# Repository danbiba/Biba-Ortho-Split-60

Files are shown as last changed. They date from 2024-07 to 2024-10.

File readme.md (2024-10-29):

# handwired/biba60




A 60% Ortholiner keyboard that can be used in a traditional form factor or split.

* Keyboard Maintainer: [Daniel Biba](https://github.com/danbiba)
* Hardware Supported: Arduino Pro Micro
* Hardware Availability: 3D Printable

## Keymap

Default Layer

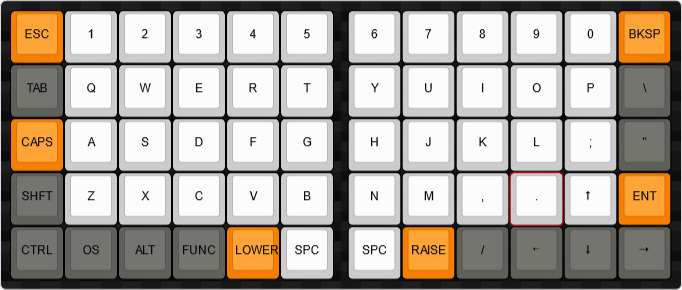
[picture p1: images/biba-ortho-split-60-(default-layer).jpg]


Lower Layer

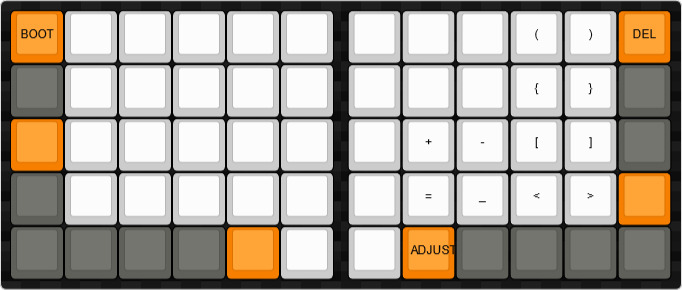
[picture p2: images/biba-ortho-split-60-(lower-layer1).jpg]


Raise Layer

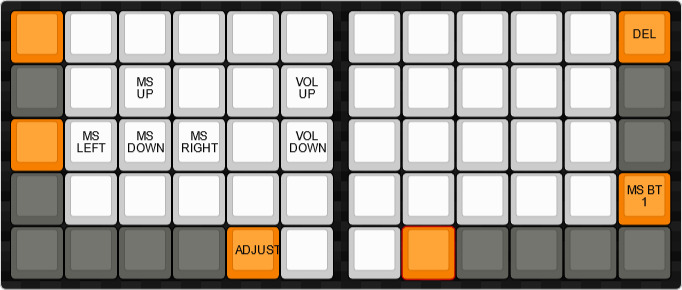
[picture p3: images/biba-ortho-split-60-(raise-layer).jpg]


Adjust Layer

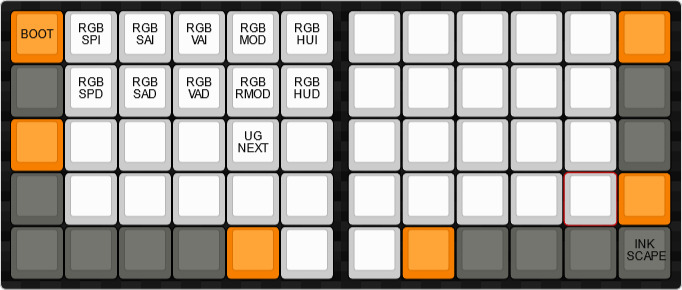
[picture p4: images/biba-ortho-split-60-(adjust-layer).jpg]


Function Layer

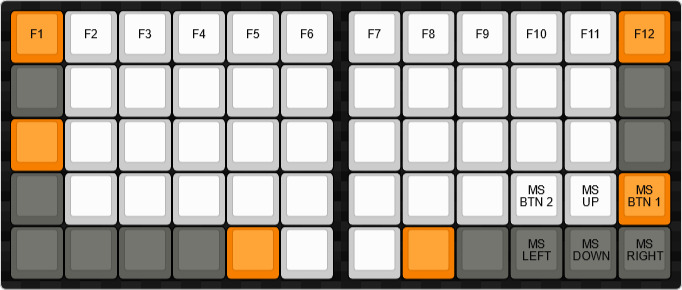
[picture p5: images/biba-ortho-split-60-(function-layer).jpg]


Inkscape Layer

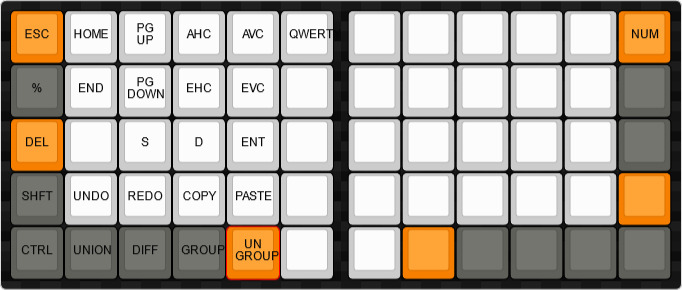
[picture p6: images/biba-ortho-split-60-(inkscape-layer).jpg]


## Setup
Place the code posted here in your qmk_firmware/keyboards/handwired/biba60 folder

Make example for this keyboard (after setting up your build environment):

    qmk compile -kb handwired/biba60 -km default

See the [build environment setup](https://docs.qmk.fm/#/getting_started_build_tools) and the [make instructions](https://docs.qmk.fm/#/getting_started_make_guide) for more information. Brand new to QMK? Start with our [Complete Newbs Guide](https://docs.qmk.fm/#/newbs).

## Bootloader

Enter the bootloader in 3 ways:

* Lower + 0,0 (if only one board is plugged in it defaults to the LEFT)
* Adjust + 0,0
* Short out pins RST and GND on the Pro Micro

## Bill of Materials
Diodes (x60): https://www.amazon.com/dp/B079KJ91JZ/?coliid=IU9YRLAUD8BYV&colid=GI9LV354TQGI&psc=1&ref_
    
Pro Mico Boards (x2): https://www.amazon.com/dp/B0B6HYLC44/?coliid=I2J23DRCUG601T&colid=GI9LV354TQGI&psc=1&ref_
    
LED Light Strips: https://www.amazon.com/dp/B01CDTED80/?coliid=I2PFQBWAX38YSN&colid=GI9LV354TQGI&psc=1&ref_
    
Switches (Epomake Wisteria Tactiles x60): https://www.amazon.com/dp/B0BZYG13Q5/?coliid=I11VNZPVFJJRM6&colid=GI9LV354TQGI&psc=1&ref_
    
2.5mm TRS cable (1x): https://www.amazon.com/dp/B09XXFYGXP?psc=1&ref=ppx_yo2ov_dt_b_product_details
    
Magnets 2x6mm (x16): https://www.amazon.com/dp/B0CCXGGTLC?psc=1&ref=ppx_yo2ov_dt_b_product_details

## Assembly

* Import the STL files in the Case folder to your favorite slicer. You will need to print the left and right plates along with the left and right cases. My keyboard was printed on an Ender 3 v3 SE. A smart thing to do is print the plates with 100% infill for a little extra strength.

* Test fit all the parts before paint (if you decide to paint) Depending on the printer the plates may warp a little, a hairdryer and a little bending should straighten them out, however the screws that assemble the case will do most of the work for you.

* Add the 2x6mm magnets to the middle of each case if you plan on having that functionality. Be careful to orient them the correct way, you may need to put a mark on each one to keep it the right way. Super glue works great to secure them in place.



* If you decide to paint the case, make sure to take your time, sand every piece and make sure to use a tough clear coat to protect it from rubbing off over time.



* Populate the plates with the switches you're gonna use. At this point I also added some rubber feet to the bottoms to make sure everything is sitting flat.



* Add the standoffs into the holes at the bottom of the cases, add the 2.5mm TRS connectors to each side. I make sure the pro micros fit in the slots on the back of each case. I used some PLA scraps and my soldering iron to secure everything in place once I was happy with how it was fitting.

 

* Time to handwire your switches. I used some scrap 16awg wire I had and used a drill to make it nice and straight after stripping. I also use a sharpie to label the rows and columns on the rear so I get them right when wiring to the Pro Micro. Another important part is to make sure the orientation of the diodes is correct, otherwise they will not function correctly.



* After all the switches are wired, time to connect each matrix to it's corresponding Pro Micro.  I also added a strip of LEDs in each side for a way to show which layer I'm using. Both sides are wired exactly the same way: 
    ### Columns are wired to pins "D4", "C6", "D7", "E6", "B4", and "B5"
    ### Rows are wired to pins "F4", "F5", "F6", "F7", and "B1"
    ### The 2.5mm connectors are wired together with the "VCC", "GND" and "D0" pins
    ### The LED lights use "VCC", "GND" and "D1" pins

  

* Flash each Pro Micro with the same .HEX file, once they are connected to each other they will know which board does what. You may need to short the "RST" and "GND" pins to enter the bootloader if the Pro Micros have never been flashed, otherwise you can hold the key at 4,4 (Lower Layer) then press the key at 0,0 (QK_BOOT) to enter the bootloader. Connect the 2 halves together with a 2.5 TRS cable, plug the keyboard into your PC with a USB C cable and enjoy!



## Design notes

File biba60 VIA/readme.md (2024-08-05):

# handwired/biba60 VIA

This is the configuration to let you adjust the Keyboard using VIA.
A lot needed to be removed from the code so that it would fit on the Pro micro, that includes a lot of the RGB effects.

# Setup

1. Compile the file, or just load the included .HEX file onto the Keyboard.
2. Connect the keyboard and open (https://usevia.app/).
3. Enable the "Show Design Tab" feature in the settings.
4. In the design tab, load the included via.json file.
5. Authorize the device, and configure it to your liking.

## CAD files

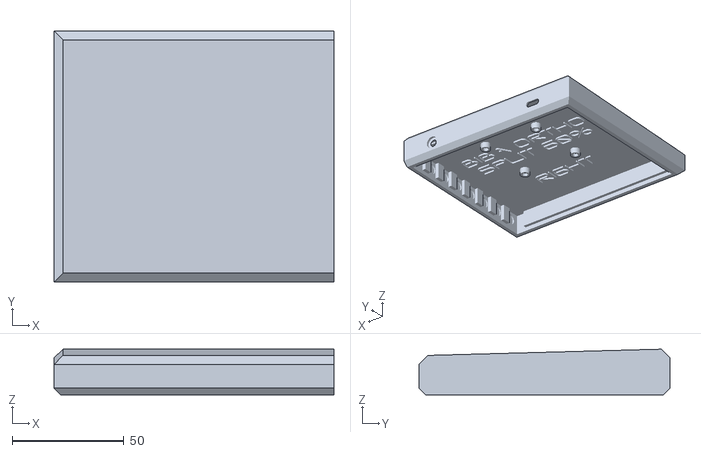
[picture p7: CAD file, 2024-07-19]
Case/Biba_Split_60_Case_Right.stl
125.1 x 112.3 x 20.4

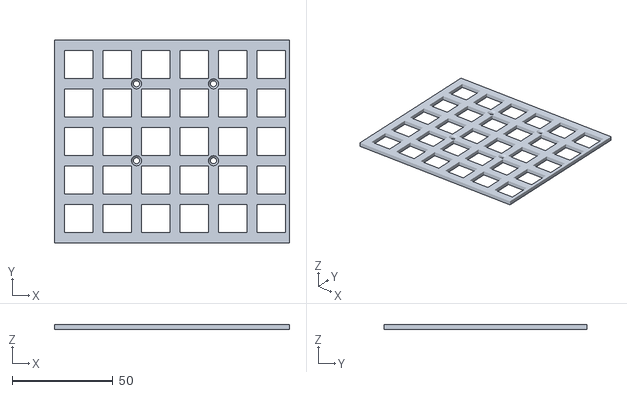
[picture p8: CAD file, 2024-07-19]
Case/Biba_Split_60_Plate_Left.stl
116.3 x 100.3 x 2.50

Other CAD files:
Case/Biba_Split_60_Plate_Right.stl
Case/Biba_Split_60_Case_Left.stl

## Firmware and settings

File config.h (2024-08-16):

#pragma once

#define MASTER_LEFT
#define SOFT_SERIAL_PIN D0

#define WS2812_DI_PIN D1 // Replace D1 with the pin you are using
#define RGBLED_NUM 12 // Total number of LEDs in your split keyboard (6 per side)
#define RGBLIGHT_SPLIT
#define RGBLIGHT_LAYERS
#define RGBLIGHT_HUE_STEP 10
#define RGBLIGHT_SAT_STEP 17
#define RGBLIGHT_VAL_STEP 17
#define RGBLIGHT_LIMIT_VAL 255
#define DYNAMIC_KEYMAP_LAYER_COUNT 6

// Enable all RGB modes
#define RGBLIGHT_EFFECT_STATIC
#define RGBLIGHT_EFFECT_BREATHING
#define RGBLIGHT_EFFECT_RAINBOW_MOOD
#define RGBLIGHT_EFFECT_RAINBOW_SWIRL
#define RGBLIGHT_EFFECT_SNAKE
#define RGBLIGHT_EFFECT_KNIGHT
#define RGBLIGHT_EFFECT_XMAS
#define RGBLIGHT_EFFECT_GRADIENT
#define RGBLIGHT_EFFECT_TWINKLE
#define RGBLIGHT_EFFECT_CHRISTMAS
#define RGBLIGHT_MODE_FAST_SPIN 35  // Example definition, ensure this matches your intended value
#define RGBLIGHT_MODE_SLOW_SPIN 25
#define RGBLIGHT_EFFECT_HUE_CYCLE
#define RGBLIGHT_EFFECT_ALTERNATING

// Define the LED layout and order
#define RGBLED_SPLIT { 6, 6 } // Number of LEDs on each half

// Define the LED positions in a continuous order
#define RGBLIGHT_LED_MAP { 0, 1, 2, 3, 4, 5, 6, 7, 8, 9, 10, 11 }

//Define mouse key mode
#define MK_KINETIC_SPEED
#define MOUSEKEY_INITIAL_SPEED 300
